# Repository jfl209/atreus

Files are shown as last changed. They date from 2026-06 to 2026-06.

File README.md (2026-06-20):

# atreus

QMK firmware for my Keyboardio Atreus + PS/2 TrackPoint mod.

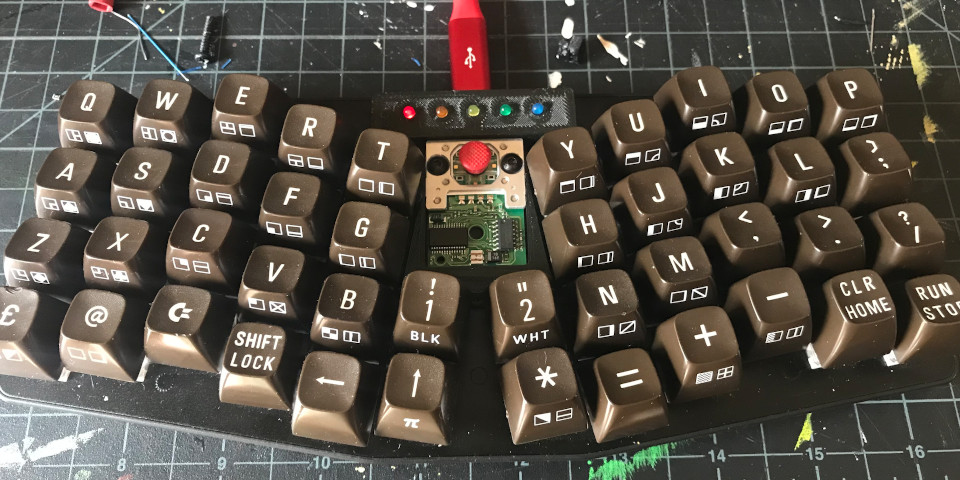
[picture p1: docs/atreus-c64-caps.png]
Atreus with TrackPoint and Commodore 64 keycaps


The original firmware source was lost. This repo was rebuilt from the running
keyboard:

- `dump/atreus-flash.hex` was read off the ATmega32U4 over Caterina/avr109.
- The QMK keymap was decoded from the dump and turned back into source under
  `keyboards/atreus_trackpoint/`.
- The trackpoint daughterboard schematic was copied in from KiCad.

If you're future-me opening this cold: start with `docs/DECODING.md` (how
the keymap was recovered) and `docs/HARDWARE.md` (what's on the PCBs).

## Hardware

- Keyboardio Atreus, ATmega32U4, Caterina bootloader
- Custom trackpoint daughterboard (KiCad files in `hardware/`, gerbers in
  `hardware/gerbers/`) with:
  - IBM-style PS/2 TrackPoint module
  - 5× WS2811-driven indicator LEDs
- 3D-printed trackpoint holder (`hardware/3d-printed/atreus trackpoint
  holder v*.stl`). Iterated through 8 versions in Jan 2021 — v8 is the last,
  presumably the keeper. The originating CAD (likely Fusion 360) was not
  recovered.

## Layout

5 layers, all built on the standard 4×12 Atreus matrix:

| # | Name | Activation | What's on it |
|---|---|---|---|
| 0 | `BASE`  | default | QWERTY |
| 1 | `SHIFT` | hold right thumb `MO(1)` | every alpha key sent as `LSFT(letter)` — thumb-driven shift |
| 2 | `NUM` | hold left thumb `MO(2)`  | digits, brackets, shifted symbols |
| 3 | `FN` | hold `MO(3)` from `SHIFT` | F1-F15, arrow cluster |
| 4 | `ADJ` | hold `MO(4)` from `NUM` | numbers + arrows combined |

Right-thumb keys are mod-tap:

- `RCTL_T(KC_QUOT)` — tap for `'`, hold for Right-Ctrl
- `RALT_T(KC_MINS)` — tap for `-`, hold for Right-Alt

Trackpoint mouse buttons are at matrix positions `[2,5]` and `[2,6]` — the
center of the third row, wired through the matrix as `KC_BTN1` / `KC_BTN2`.

See `keyboards/atreus_trackpoint/keymaps/default/keymap.c` for the full
keymap.

## Building

This repo contains only the custom keyboard folder. Drop it into a QMK
checkout to build:

```sh
# 1. Get QMK
git clone https://github.com/qmk/qmk_firmware.git
cd qmk_firmware
make git-submodule        # pulls chibios, lufa, etc.

# 2. Link in this keyboard
ln -s ~/git/atreus/keyboards/atreus_trackpoint keyboards/atreus_trackpoint

# 3. Build
qmk compile -kb atreus_trackpoint -km default
# (output: atreus_trackpoint_default.hex in the repo root)
```

**Before flashing a fresh build**, confirm the trackpoint pins in
`keyboards/atreus_trackpoint/config.h` are correct. They were guessed, not
recovered. See `docs/HARDWARE.md` § "How to verify the pins".

If a new QMK release renamed something and the build breaks, the original
firmware was built around early-2021 QMK — pin to a commit from that window
and port forward in small steps.

## Flashing

```sh
# Restore the captured backup
./flash.sh

# Or flash a fresh build
./flash.sh path/to/atreus_trackpoint_default.hex
```

To enter bootloader mode: hold `Fn+Esc` if the binding survived in your
build, otherwise press the reset button on the bottom of the keyboard —
it's accessible through a small hole in the bottom plate, poke it with a
paperclip.

## Layout of this repo

```
.
├── README.md
├── flash.sh                          # one-command flash helper
├── dump/
│   ├── atreus-flash.hex              # working firmware backup (re-flashable)
│   └── atreus-flash.bin              # raw binary, same content
├── docs/
│   ├── DECODING.md                   # how the keymap was recovered from the dump
│   └── HARDWARE.md                   # schematic notes, pin assignments, gotchas
├── hardware/
│   ├── atreus_trackpoint.{sch,kicad_pcb,pro,net,lib}
│   ├── 3d-printed/                   # printable STLs (v1-v8) of trackpoint holder
│   └── gerbers/                      # PCB fab files
├── keyboards/
│   └── atreus_trackpoint/            # QMK keyboard (symlink into qmk_firmware/keyboards)
│       ├── atreus_trackpoint.{c,h}
│       ├── config.h                  # matrix + trackpoint pin defs (TODOs!)
│       ├── rules.mk
│       ├── info.json
│       └── keymaps/default/
│           ├── keymap.c              # 5-layer keymap
│           └── rules.mk
└── tools/
    └── decode_keymap.py              # the decoder used on the dump
```

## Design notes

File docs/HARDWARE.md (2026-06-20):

# Hardware notes

## Keyboard

Keyboardio Atreus, production model. ATmega32U4 @ 16MHz, Caterina bootloader,
4×12 diode matrix (`COL2ROW`).

Matrix pins (from upstream `keyboards/keyboardio/atreus/info.json`):

    Rows: F6, F7, B1, B2
    Cols: B6, B5, D7, C6, D6, F5, F4, B7, D4, E6, D2, D3

Free GPIO pins (everything else on the chip):

    B3, B4, C7, D0, D1, D5, E2, F0, F1

## Trackpoint daughterboard

KiCad project in `hardware/atreus_trackpoint.sch`. Lives between the Atreus
mainboard and a PS/2 IBM-style TrackPoint module. Bridges two roles:

1. **PS/2 passthrough** — the trackpoint's CLK / DATA / RST / VCC / GND wires
   land on TP2-TP6 on one side. CLK and DATA continue through to TP8/TP9 on
   the "To Keyboard" side. The board adds pull-up resistors (R2 on CLK, R3 on
   DATA, R1 on RST) and a power-on reset RC network (R1 + C1 on RST). The
   trackpoint's RST is generated locally — the MCU does **not** drive it.

2. **Indicator LEDs** — two WS2811 driver chips (U1, U2) drive a chain of 5
   through-hole LEDs (D1-D5). DIN comes in from the keyboard side on TP7
   (signal labeled "LED"). The LED chain is independent of the trackpoint.

### Pads exposed on the "To Keyboard" side

| Pad | Signal | Connects to (MCU pin) |
|---|---|---|
| TP7 | LED | **TODO: trace** (guessed `D5`) |
| TP8 | CLK | **TODO: trace** (guessed `D1` = INT1) |
| TP9 | DATA | **TODO: trace** (guessed `D0`) |
| TP10  | VCC | +5V |
| TP11  | GND | GND |

### Pads exposed on the "To Trackpoint" side

| Pad | Signal | Notes |
|---|---|---|
| TP2 | CLK | with pull-up R2 |
| TP3 | DATA | with pull-up R3 |
| TP4 | RST | driven by R1+C1, also pulled up to VCC |
| TP5 | VCC | +5V |
| TP6 | GND | |

### Constraints when picking MCU pins

- `PS2_CLOCK_PIN` **must** be an external interrupt pin on the ATmega32U4:
  `D0` (INT0) or `D1` (INT1). The other available INT pins (INT2/3/6) are in
  use by USB or fixed peripherals.
- `PS2_DATA_PIN` can be any free digital pin.
- `WS2812_DI_PIN` can be any free digital pin; PWM-capable pins help if
  using the `pwm` driver, but `bitbang` works anywhere.

### How to verify the pins

Easiest, no disassembly: short the trackpoint's CLK or DATA wire to GND with
a multimeter probe while watching `qmk console` output, and see which pin
the PS/2 init complains about. Or: open the case, identify the three wires
coming off the daughterboard's "To Keyboard" pads, and follow them with a
multimeter in continuity mode to the matching pin on the Atreus MCU.

If neither is practical, the dumped firmware *does* contain the PS/2 init
code that touches the actual PORT/DDR/PIN registers — a short avr-objdump
+ search session would recover the pins definitively.

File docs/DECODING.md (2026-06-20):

# How the keymap and firmware identity were recovered

The original source for this firmware was lost. This document captures what
was determined by inspecting the on-chip firmware, so future-you (or anyone
else opening this repo) can audit the reconstruction.

## Recovering the binary

The keyboard's ATmega32U4 was put into Caterina bootloader mode (poked the
reset button through the hole in the bottom plate with a paperclip). Caterina enumerates as a USB CDC
serial device for ~8 seconds. `avrdude` over the `avr109` protocol read the
full 32KB flash:

```
avrdude -p atmega32u4 -c avr109 -P /dev/cu.usbmodematreus1 -b 57600 \
        -D -U flash:r:atreus-flash.hex:i
```

Output: `dump/atreus-flash.hex` (Intel HEX, 32768 bytes of flash). The raw
`dump/atreus-flash.bin` was produced from the HEX for easier analysis.

## Identifying the firmware as QMK

The dump contained almost no embedded strings:

- `jonlorusso`, `jonlorusso@gmail.com` — used as USB iManufacturer/iSerial
- `CATERINA` — bootloader signature
- The rest of the binary is code/data, no plugin or focus-protocol strings

Kaleidoscope builds embed many plugin / focus strings. The absence of those,
combined with the keymap layout pattern below, points to **QMK**.

USB descriptors visible at runtime via `ioreg`:

    Vendor: Keyboardio  (VID 0x1209)
    Product: Atreus     (PID 0x2303)

These match both Kaleidoscope's stock Atreus build and QMK's
`keyboards/keyboardio/atreus` — so VID/PID alone is ambiguous.

## Decoding the keymap

QMK stores `keymaps` as a `uint16_t[LAYERS][ROWS][COLS]` array in PROGMEM.
For the Atreus that's 4×12×2 = 96 bytes per layer.

The QWERTY top row `Q W E R T _ _ Y U I O P` translates to HID usage codes
`14 00 1a 00 08 00 15 00 17 00 00 00 00 00 1c 00 18 00 0c 00 12 00 13 00`.
Searching the binary for that signature found a unique match at offset
**0x00D5**, immediately following the user's email string in flash.

`tools/decode_keymap.py` walks forward from there and decodes layers using
QMK's old (pre-2022) keycode encoding:

| range | meaning |
| --- | --- |
| `0x0000-0x00FF`  | basic HID keycodes (`KC_A` = 0x04, etc.) |
| `0x0100-0x1FFF`  | modifier-prefixed (`LSFT(KC_X)` = `0x0200 \| 0x????`) |
| `0x4000-0x4FFF`  | Layer-Tap |
| `0x5100-0x51FF`  | Momentary layer (`MO(N)`) |
| `0x6000-0x7FFF`  | Mod-Tap (5-bit mod in upper byte) |

5 clean layers were decoded (`L_BASE`, `L_SHIFT`, `L_NUM`, `L_FN`, `L_ADJ`).
Two more "layers" past those decode to plausible-looking but likely-garbage
keycodes (e.g. one of them spells `F U C K 4` on the top row, which is more
likely PROGMEM data adjacent to the keymap than an intentional easter egg).
The reconstruction stops at 5 layers.

### Notable findings

- The center thumb-gap positions in row 2 (matrix `[2,5]` and `[2,6]`) hold
  custom keycodes `0xF4` and `0xF5` in every layer. On a stock Atreus those
  matrix slots are `KC_NO`. These are very likely the **trackpoint mouse
  buttons** wired through the matrix — in the reconstructed source they're
  expressed as `KC_BTN1` / `KC_BTN2` (the `process_record_user` translation
  the original firmware presumably did becomes unnecessary).
- Right-thumb mod-taps: `RCTL_T(KC_QUOT)` and `RALT_T(KC_MINS)`. Tap for the
  symbol, hold for the modifier.
- Layer 1 (the SHIFT layer) is entirely `LSFT(letter)` — a thumb-driven
  shift in place of a pinky-driven shift.

## Pin assignments for the trackpoint

The schematic (`hardware/atreus_trackpoint.sch`) shows the daughterboard's
"To Keyboard" pads expose LED + CLK + DATA + VCC + GND. Which MCU pins those
five pads were soldered to was **not** recoverable from the dump without
disassembly of the AVR PORT/DDR register accesses in the compiled PS/2 code.

`keyboards/atreus_trackpoint/config.h` contains best-guess pins (`PS2_CLOCK_PIN
D1`, `PS2_DATA_PIN D0`, `WS2812_DI_PIN D5`) with a `TODO` note. Verify by
tracing the actual daughterboard wires before flashing a fresh build.

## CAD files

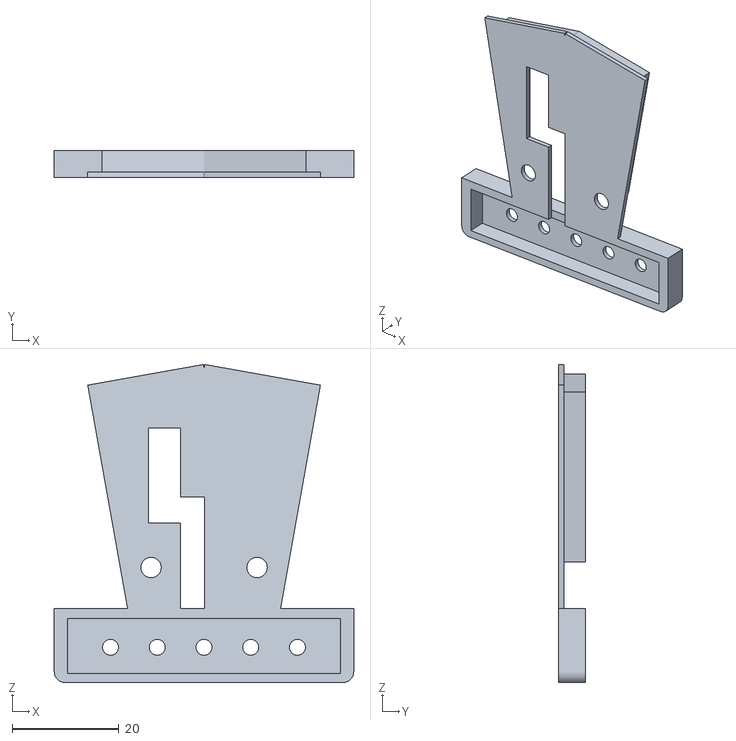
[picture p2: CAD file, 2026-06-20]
hardware/3d-printed/atreus trackpoint holder v8.stl
56.2 x 5.00 x 59.6

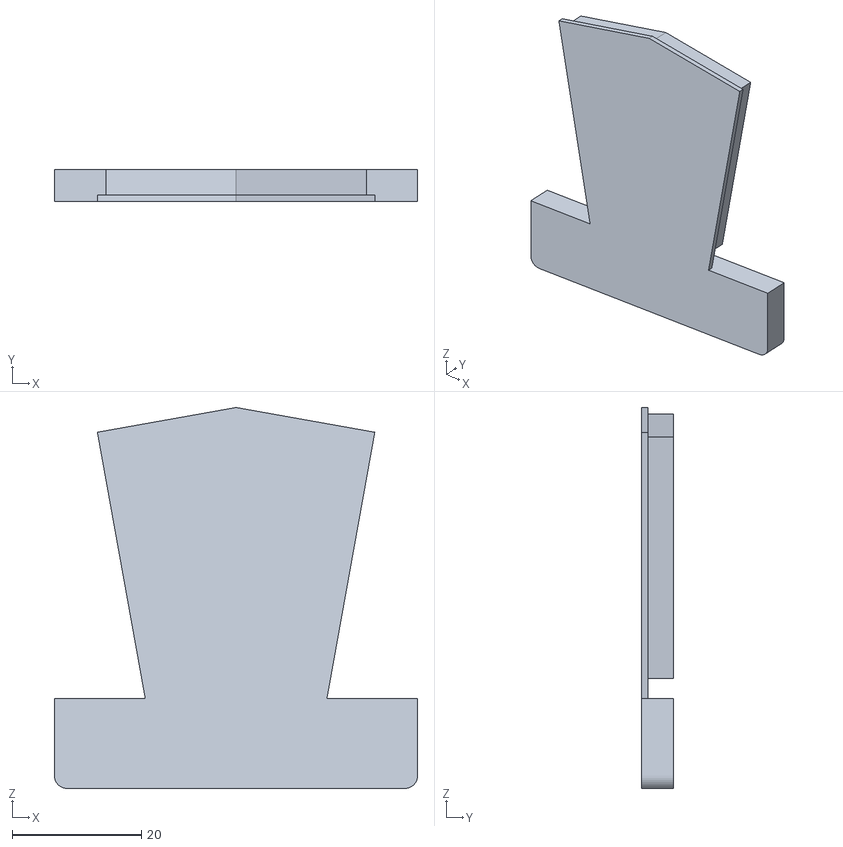
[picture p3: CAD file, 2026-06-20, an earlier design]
hardware/3d-printed/atreus trackpoint holder v2.stl
56.2 x 5.00 x 58.9

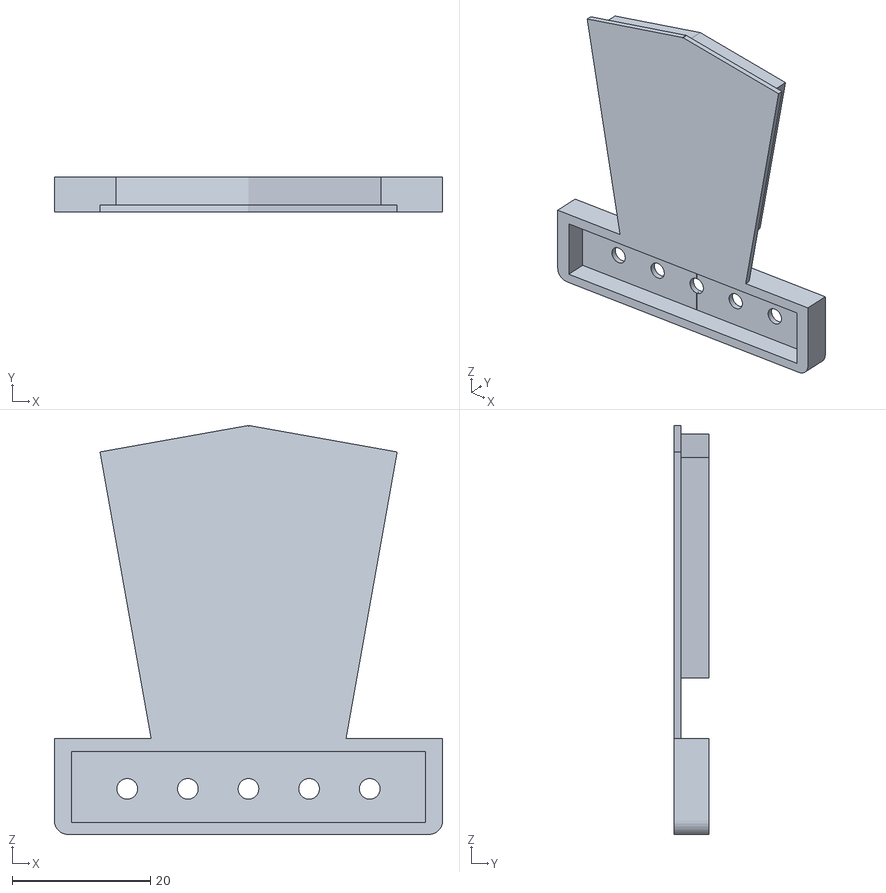
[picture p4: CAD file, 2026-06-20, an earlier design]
hardware/3d-printed/atreus trackpoint holder v4.stl
56.2 x 5.00 x 59.1

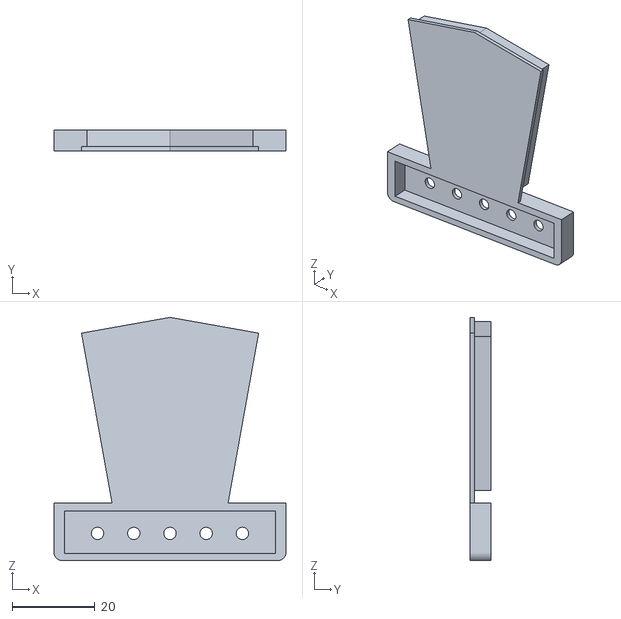
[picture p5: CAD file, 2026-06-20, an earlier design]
hardware/3d-printed/atreus trackpoint holder v3.stl
56.2 x 5.00 x 58.9

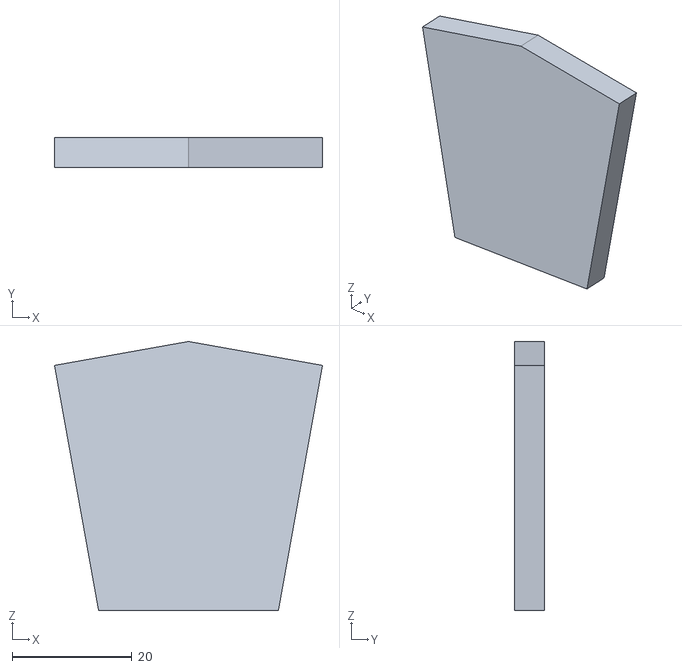
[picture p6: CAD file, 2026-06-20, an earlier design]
hardware/3d-printed/atreus trackpoint holder v1.stl
44.8 x 5.00 x 45.0

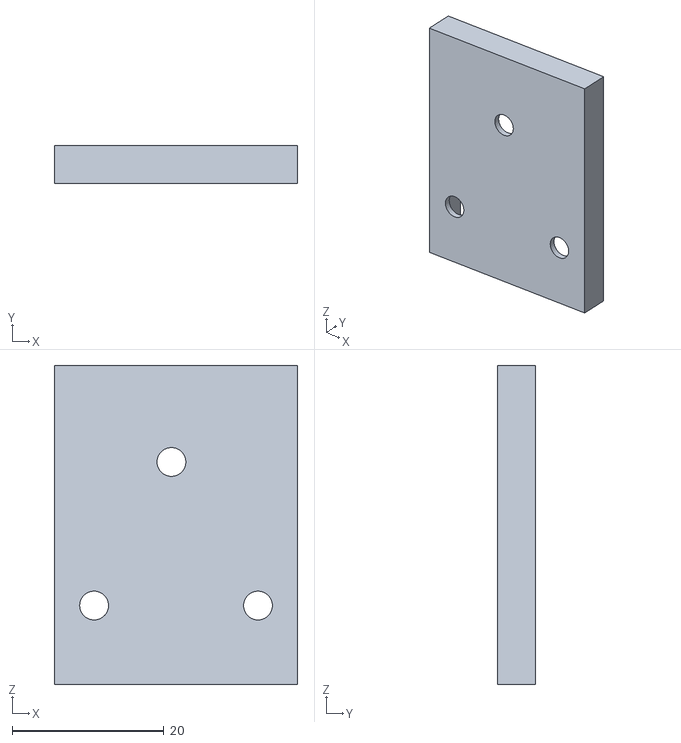
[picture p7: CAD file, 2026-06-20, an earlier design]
hardware/3d-printed/atreus trackpoint holder v1 copy.stl
32.0 x 5.00 x 42.0

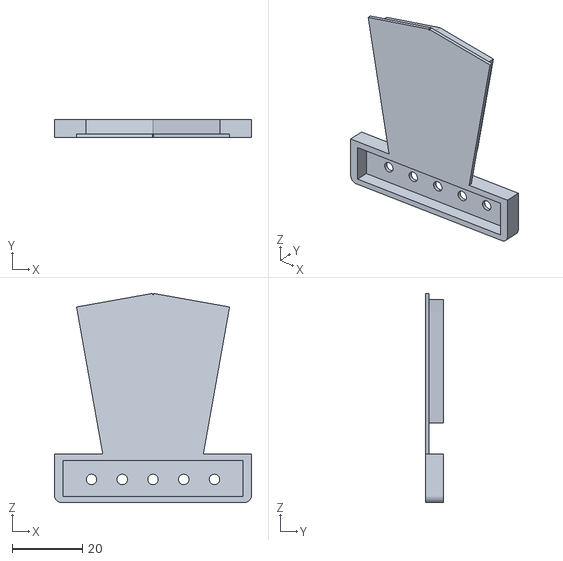
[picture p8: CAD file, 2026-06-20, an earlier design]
hardware/3d-printed/atreus trackpoint holder v7.stl
56.2 x 5.00 x 59.6

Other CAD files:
hardware/3d-printed/atreus trackpoint holder v5.stl

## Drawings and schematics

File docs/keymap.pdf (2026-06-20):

# Layer 0 — BASE

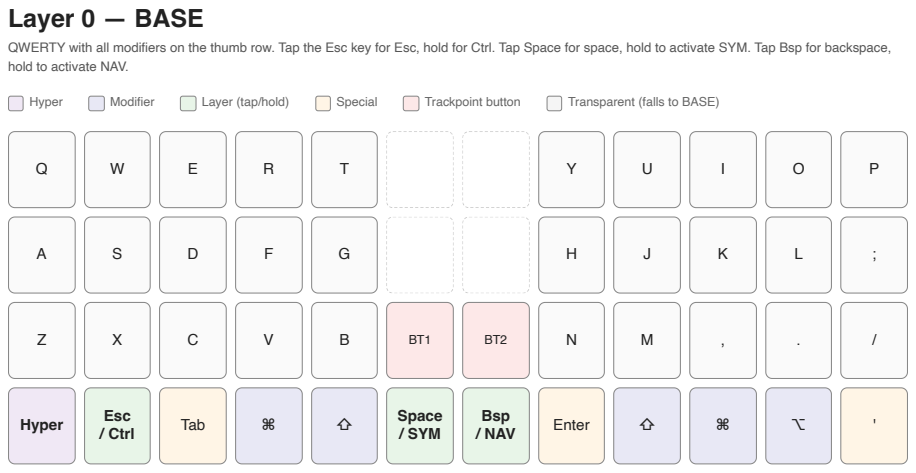
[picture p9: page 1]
Hyper; Modifier; Layer (tap/hold); Special; Trackpoint button; Transparent (falls to BASE); Esc / Ctrl; Tab; Space / SYM; Bsp / NAV; Enter

QWERTY with all modifiers on the thumb row. Tap the Esc key for Esc, hold for Ctrl. Tap Space for space, hold to activate SYM. Tap Bsp for backspace,
hold to activate NAV.

# Layer 1 — NAV (hold the Backspace key)

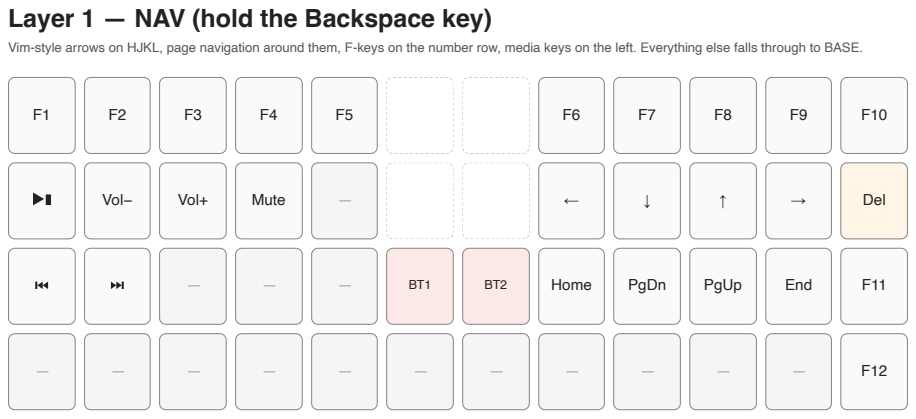
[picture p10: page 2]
Vol−; Vol+; Mute; Del; Home; PgDn; PgUp; End

Vim-style arrows on HJKL, page navigation around them, F-keys on the number row, media keys on the left. Everything else falls through to BASE.

# Layer 2 — SYM (hold the Space key)

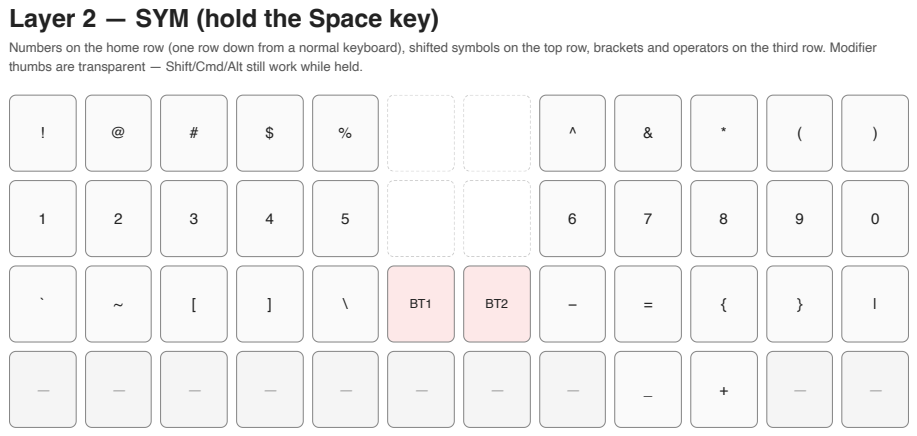
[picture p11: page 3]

Numbers on the home row (one row down from a normal keyboard), shifted symbols on the top row, brackets and operators on the third row. Modifier
thumbs are transparent — Shift/Cmd/Alt still work while held.

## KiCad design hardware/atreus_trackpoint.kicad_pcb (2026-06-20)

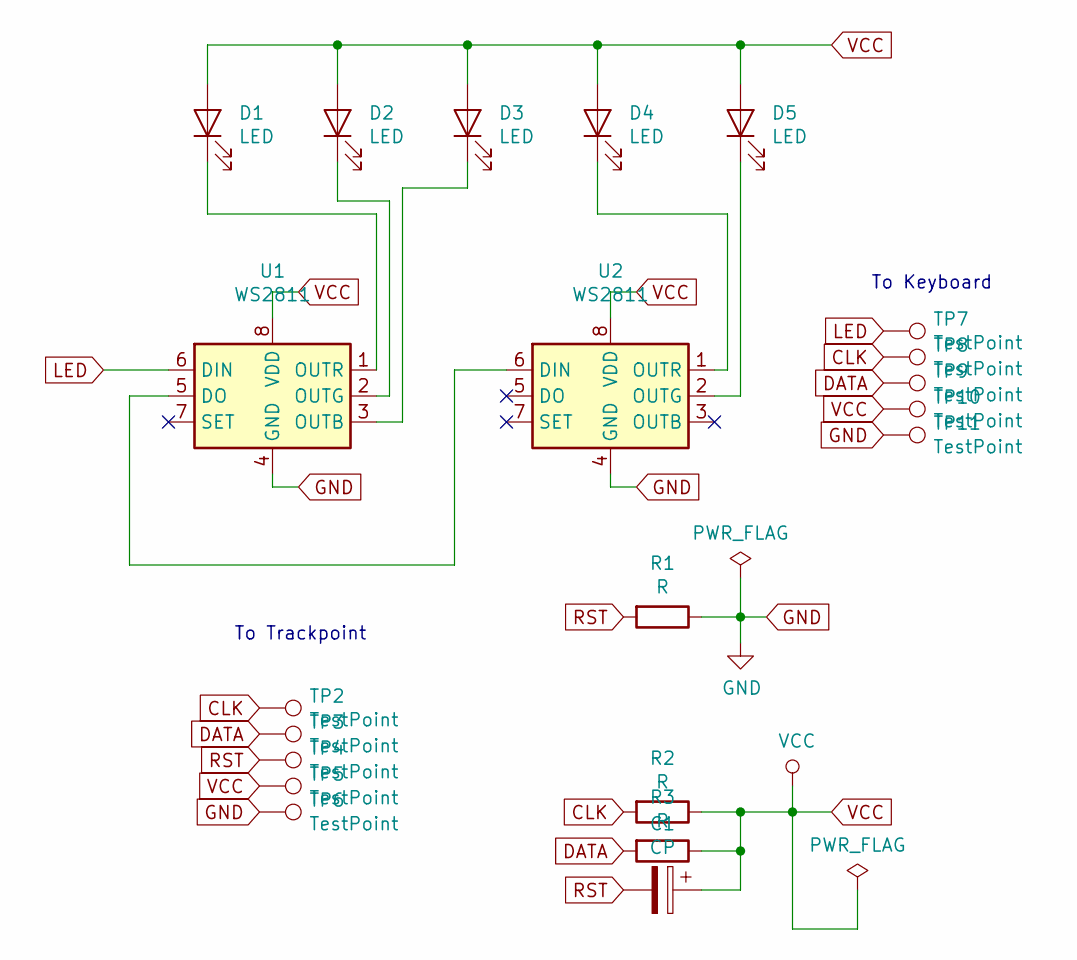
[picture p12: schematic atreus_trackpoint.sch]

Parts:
C1: CP; C_1206_3216Metric
D1, D2, D3, D4, D5: LED; LED_D3.0mm
R1, R2, R3: R; R_0805_2012Metric
TP2, TP3, TP4, TP5, TP6, TP7, TP8, TP9, TP10, TP11: TestPoint; TestPoint_Pad_1.0x1.0mm
U1, U2: WS2811; SOP-8_3.76x4.96mm_P1.27mm

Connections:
CLK: R2.2, TP2.1, TP8.1
DATA: R3.2, TP3.1, TP9.1
GND: R1.1, TP6.1, TP11.1, U1.4 (GND), U2.4 (GND)
LED: TP7.1, U1.6 (DIN)
unnamed: D1.1 (K), U1.1 (OUTR)
unnamed: D2.1 (K), U1.2 (OUTG)
unnamed: D3.1 (K), U1.3 (OUTB)
unnamed: D4.1 (K), U2.1 (OUTR)
unnamed: D5.1 (K), U2.2 (OUTG)
unnamed: U1.5 (DO), U2.6 (DIN)
RST: C1.2, R1.2, TP4.1
VCC: C1.1, D1.2 (A), D2.2 (A), D3.2 (A), D4.2 (A), D5.2 (A), R2.1, R3.1, TP5.1, TP10.1, U1.8 (VDD), U2.8 (VDD)

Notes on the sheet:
To Trackpoint
To Keyboard

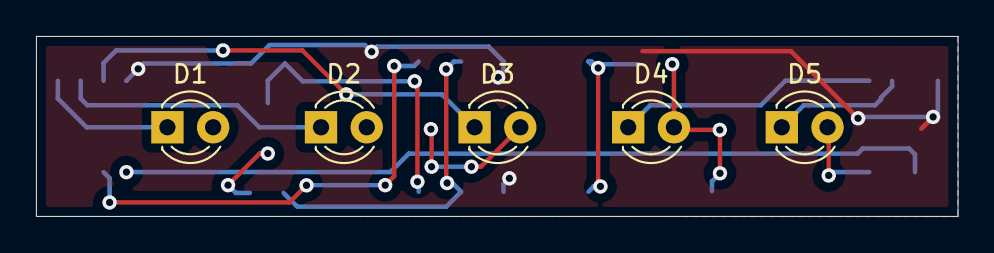
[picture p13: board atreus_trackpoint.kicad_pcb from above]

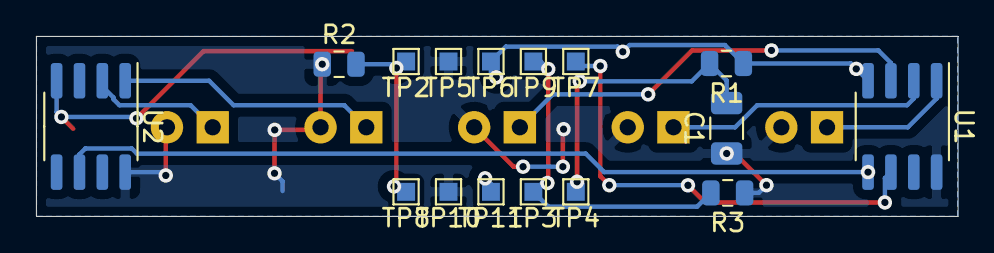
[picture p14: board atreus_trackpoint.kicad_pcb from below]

Board: 2 copper layers, 51.2 x 10.0 mm, 21 parts (16 on the bottom side), 12 nets.

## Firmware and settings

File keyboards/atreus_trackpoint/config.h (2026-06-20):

#pragma once

/*
 * Atreus + TrackPoint (PS/2)
 *
 * Hardware: Keyboardio Atreus (production, ATmega32U4) with a custom
 * trackpoint daughterboard hanging off a few free GPIO pins.
 * See hardware/atreus_trackpoint.sch.
 */

/* Matrix — identical to stock Keyboardio Atreus.
 * If a newer QMK ships with different pin defs for keyboardio/atreus, prefer those. */
#define MATRIX_ROWS 4
#define MATRIX_COLS 12
#define MATRIX_ROW_PINS { F6, F7, B1, B2 }
#define MATRIX_COL_PINS { B6, B5, D7, C6, D6, F5, F4, B7, D4, E6, D2, D3 }
#define DIODE_DIRECTION COL2ROW

/* PS/2 trackpoint pins.
 *
 * TODO: VERIFY by tracing the daughterboard wiring back to the Atreus MCU.
 * The schematic (hardware/atreus_trackpoint.sch) shows the daughterboard's
 * "To Keyboard" side exposes: LED, CLK, DATA, VCC, GND. We don't know which
 * MCU pins they were soldered to.
 *
 * Constraints:
 *   - CLK must be on an external interrupt pin: D0 (INT0) or D1 (INT1)
 *   - DATA can be any digital GPIO
 *   - LED (WS2811 DIN) can be any digital GPIO; PWM-capable preferred
 *
 * Free pins on the Keyboardio Atreus (not in MATRIX_ROW_PINS / MATRIX_COL_PINS):
 *   B3, B4, C7, D0, D1, D5, E2, F0, F1
 *
 * Current guesses (most likely combo given the constraints):
 */
#define PS2_CLOCK_PIN  D1   /* INT1 */
#define PS2_DATA_PIN   D0
#define WS2812_DI_PIN  D5   /* feeds the daughterboard's WS2811 chain */

/* PS/2 driver — interrupt mode is the standard choice on AVR */
#define PS2_DRIVER interrupt
#define PS2_MOUSE_INIT_DELAY 1000  /* trackpoint needs a beat after power-up */

/* WS2811/WS2812 indicator LEDs on the daughterboard (D1..D5 in schematic = 5 LEDs) */
#define RGBLIGHT_LED_COUNT 5
#define RGBLIGHT_DEFAULT_MODE RGBLIGHT_MODE_STATIC_LIGHT

/* USB identifiers — match the keyboard's current USB descriptors so the host
 * keeps recognizing it as the same device (and karabiner rules etc. stay valid). */
#define VENDOR_ID    0x1209
#define PRODUCT_ID   0x2303
#define DEVICE_VER   0x0001
#define MANUFACTURER "Keyboardio"
#define PRODUCT      "Atreus"

/* Debounce */
#define DEBOUNCE 5

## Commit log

2026-06-20 Initial commit: reconstructed firmware + source repo
    Source for the original QMK firmware running on my Keyboardio Atreus +
    trackpoint mod was lost. Rebuilt from the running keyboard:
    - dump/atreus-flash.hex captured off the ATmega32U4 via Caterina/avr109
    - 5-layer QMK keymap decoded out of the dump and re-emitted as source
    under keyboards/atreus_trackpoint/keymaps/default/keymap.c
    - Trackpoint daughterboard KiCad files copied in from iCloud
    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
    [atreus_trackpoint.kicad_pcb, atreus_trackpoint.sch]
2026-06-20 Add 3D-printed trackpoint holder STLs, individual gerbers, and photo
    - hardware/3d-printed/: 8 STL iterations of the trackpoint holder (v8 is
    the final). The originating CAD (Fusion 360, per memory) wasn't found
    on this machine — possibly on an old laptop or never persisted to disk.
    - hardware/gerbers/: individual gerber + drill files (replaces gerber.zip)
    - docs/atreus-c64-caps.png: photo of the keyboard with C64 keycaps and
    trackpoint visible
    [atreus trackpoint holder v1 copy.stl, atreus trackpoint holder v1.stl, atreus trackpoint holder v2.stl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]
2026-06-20 Fix reset-button instructions: accessible via hole in bottom plate
    No disassembly needed — poke through with a paperclip.
2026-06-20 Rewrite keymap to 'Mac-Natural' 3-layer layout + add printable PDF reference
    Replaces the reconstructed 5-layer keymap (which had quirky behaviors like
    LSFT-on-every-key shift layer) with a clean, ergonomic layout designed for a
    Mac + vim developer:
    - BASE: QWERTY, modifiers on thumb row, Hyper on bottom-left pinky
    - NAV (hold Bsp): arrows on HJKL, page nav, F-keys, media
    - SYM (hold Spc): numbers on home row, shifted symbols on top row, brackets
    - Mod-taps: Esc->Ctrl, Space->SYM, Bsp->NAV
    Adds docs/keymap.pdf (and the docs/keymap.html source + tools/gen_keymap_pdf.py
    generator), so the layout can be printed and pinned next to the keyboard while
    relearning, and regenerated if the keymap ch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
